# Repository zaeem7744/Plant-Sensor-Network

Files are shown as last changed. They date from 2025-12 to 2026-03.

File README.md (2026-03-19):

# :seedling: Plant Monitoring Sensor Network -- Complete IoT System








A production-ready full-stack IoT environmental monitoring system with **13 sensors**, battery + solar power, deep-sleep optimization achieving **~92% power savings**, and a real-time web dashboard. The system wakes every 30 minutes, reads all sensors, transmits data over Wi-Fi, and goes back to sleep -- designed to run **indefinitely on solar power**.

> **This is the firmware repository.** See also: [Backend API](https://github.com/zaeem7744/Plant-Sensor-Network-Backend) | [Web Dashboard](https://github.com/zaeem7744/Plant-Sensor-Network-Web-Dashboard)

---

## :camera: Screenshots

### Overview Dashboard -- System Status & 24h Averages
Shows total sensors, online/offline count, 1,786+ measurements recorded, and live sensor cards with real-time readings.

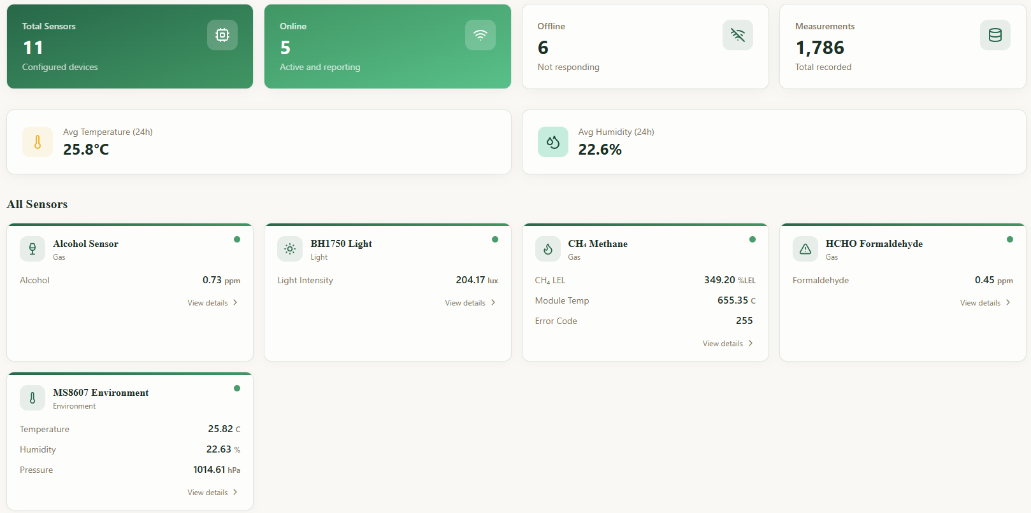
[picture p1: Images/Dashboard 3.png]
Dashboard Overview


### All Sensors View -- Live Readings Grid
13 environmental sensors displayed with real-time values, status indicators (green = online), and "View details" drill-down.

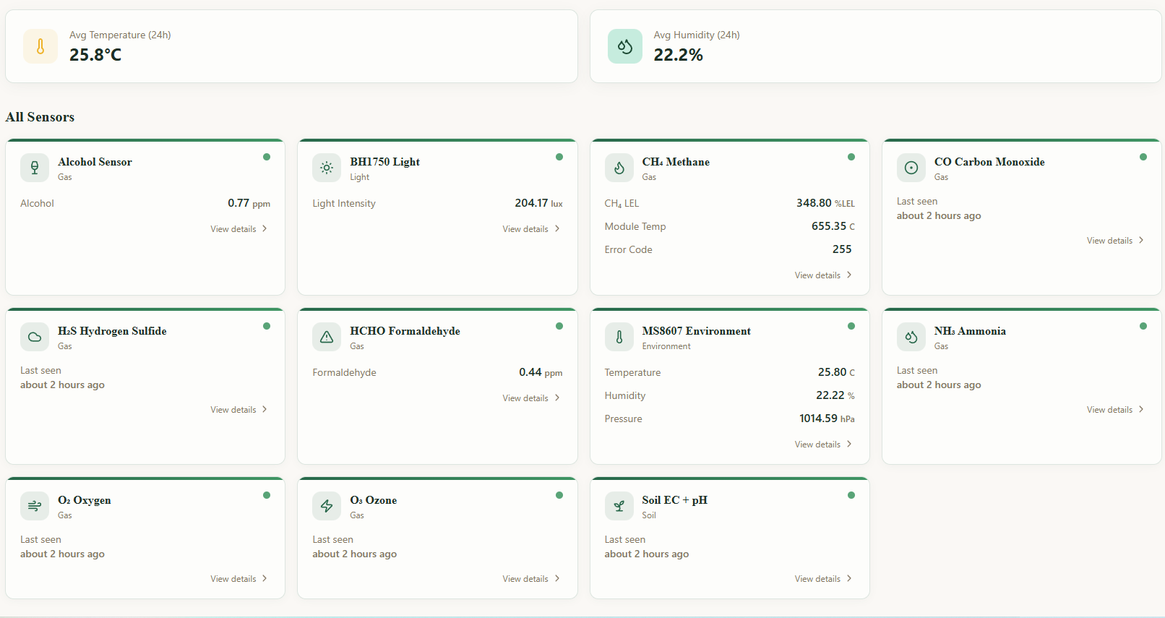
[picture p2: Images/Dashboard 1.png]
All Sensors


### Sensor Detail -- Historical Charts & Statistics
Individual sensor view with configurable time range (24h / 7d / 30d / All), interactive time-series chart, and min/max/avg statistics.

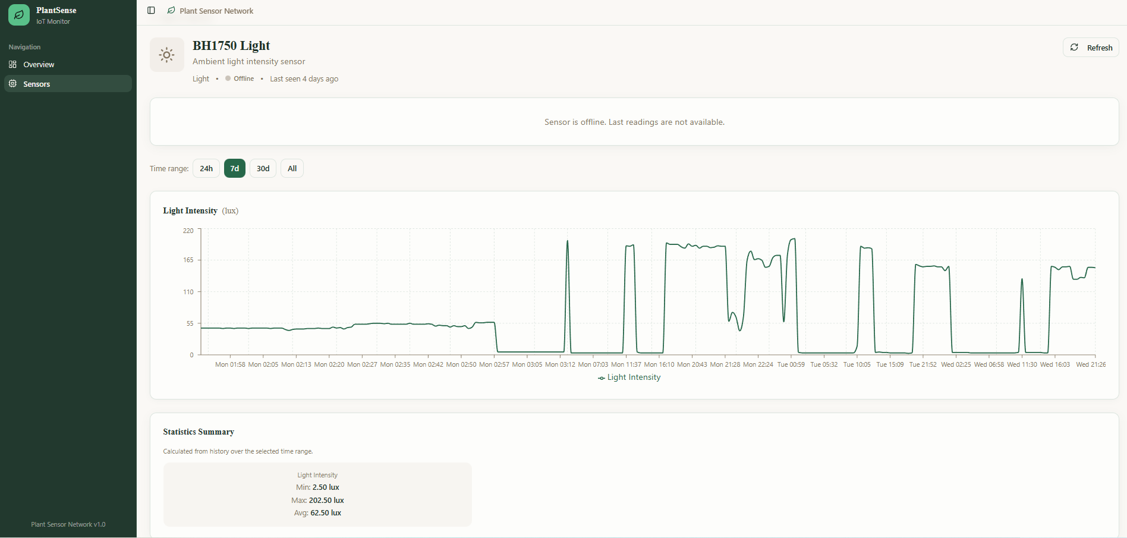
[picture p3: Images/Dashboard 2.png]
Sensor Detail


### Gas Sensors -- Category Filter
Filter sensors by category: Environment, Light, Gas, Soil. Showing 8 gas sensors monitoring CO, CH4, NH3, H2S, HCHO, O2, O3, and Alcohol.

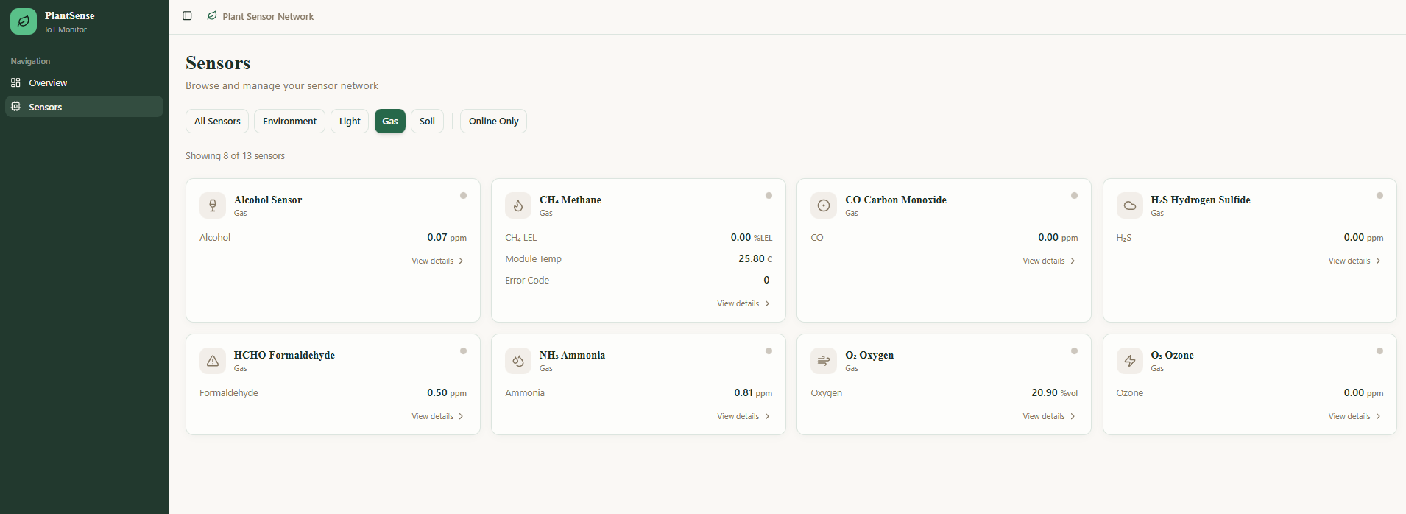
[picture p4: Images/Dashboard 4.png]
Gas Sensors


### Backend API -- FastAPI + Uvicorn Running
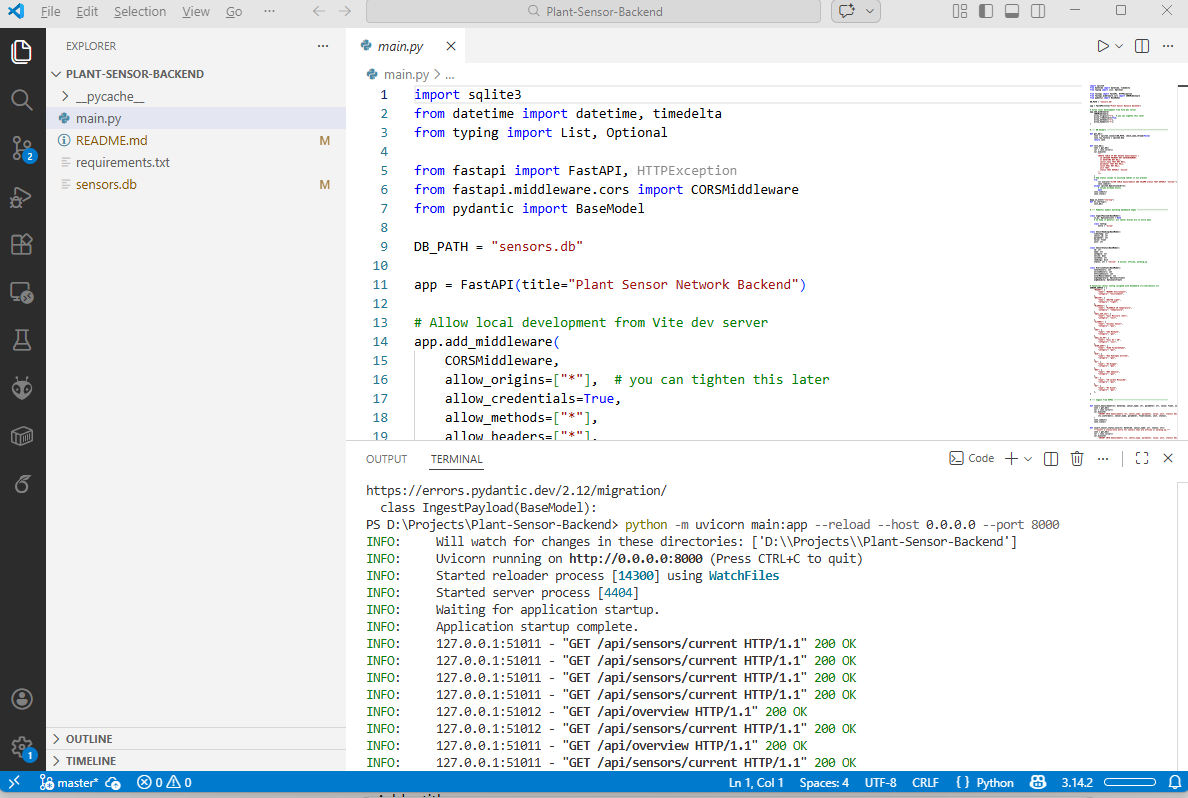
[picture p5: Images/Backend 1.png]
Backend


### Hardware Development -- Firmware & Sensor Testing
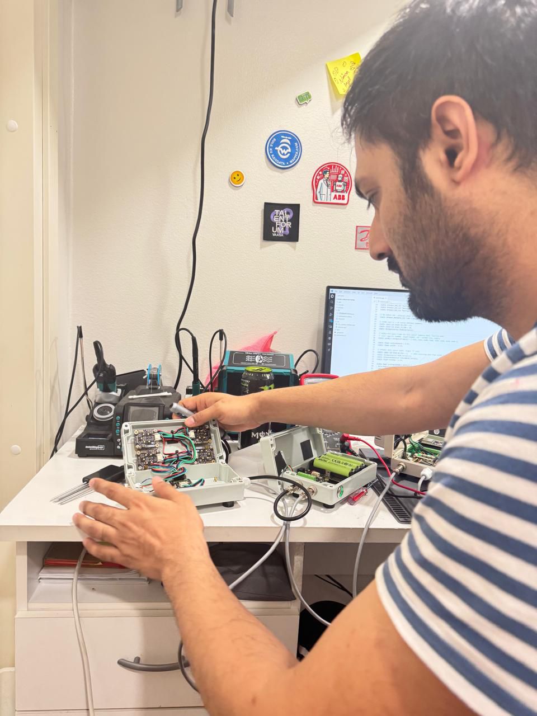
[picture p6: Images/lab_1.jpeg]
Firmware Development


### Lab Setup -- Oscilloscope, Multimeter & Sensor Node Enclosures
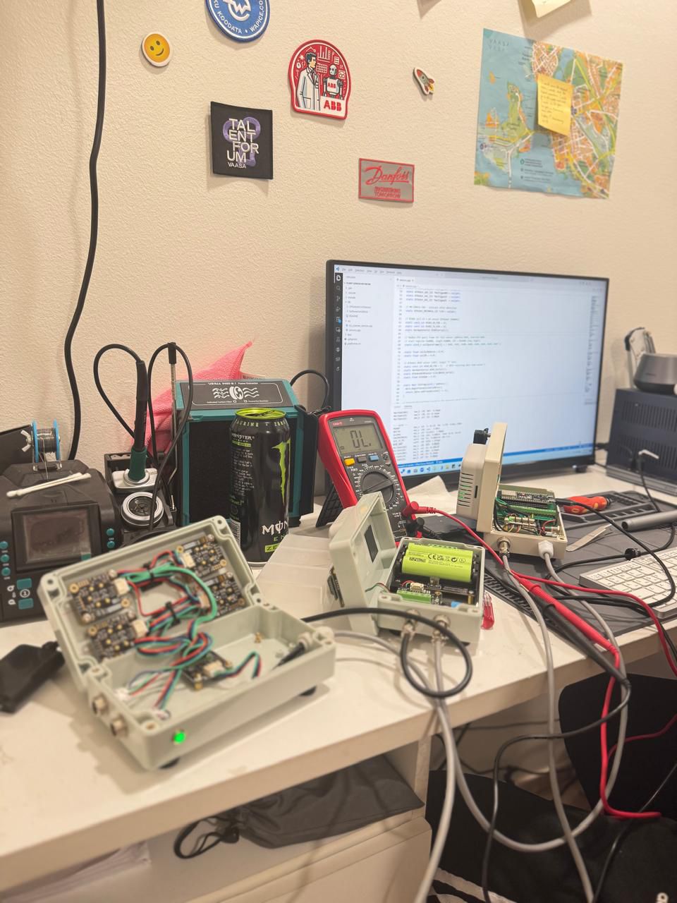
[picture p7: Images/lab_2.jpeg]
Lab Setup


### Hardware Debugging -- Probing Sensor Nodes
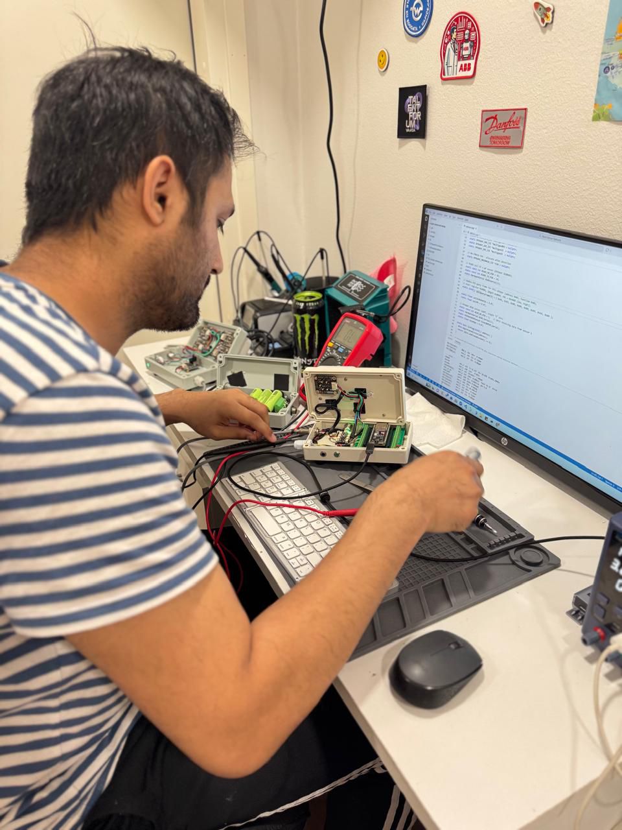
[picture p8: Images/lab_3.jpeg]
Hardware Testing


---

## :zap: Key Highlights

- **13 Environmental Sensors** with I2C multiplexing (2x TCA9548A) for address conflict resolution
- **~92% power savings** via deep sleep + MOSFET-switched sensor power rail
- **Solar-powered indefinite runtime** -- 10W panel generates 4.3x daily consumption
- **Battery backup** -- 3x 18650 cells (8,700 mAh), 5+ days without sunlight
- **Dual measurement cycle** -- status check then data upload for reliability
- **Production-ready dashboard** with real-time updates, historical charts, and statistics
- **Full-stack architecture** -- ESP32-S3 firmware + FastAPI backend + React/TypeScript frontend

---

## :building_construction: System Architecture

```
10W Solar Panel --> Charge Controller --> 3x 18650 Battery (8700 mAh)
                                              |
                                        Boost Converter (3.7V --> 5V)
                                              |
                    +-------------------------+-------------------------+
                    |                                                   |
              ESP32-S3 MCU                                   N-Channel MOSFET (GPIO 14)
         (always powered, ~20mA sleep)                              |
                    |                                        Sensor 5V Rail
                    |                                              |
              +-----+-----+                              All 13 Sensors (~300mA active)
              |           |
         Timer Wake   Button Wake -----> Double Measurement Cycle
         (30 min)     (GPIO 7)                    |
                                           WiFi POST --> FastAPI Backend --> SQLite DB
                                                                |
                                                    React Dashboard (live updates)
```

### Power States

| State | Current Draw | Duration | Description |
|---|---|---|---|
| **Active** | ~300 mA | ~8 sec | Sensors ON, reading + WiFi transmit |
| **Deep Sleep** | ~26 mA | ~1792 sec | ESP32 sleep + sensors OFF via MOSFET |
| **Average per cycle** | -- | 30 min | 13.62 mAh per cycle |
| **Daily consumption** | -- | 24h | ~653 mAh @ 5V (~3.27 Wh) |
| **Solar generation** | -- | 5h sun | ~2,800 mAh/day (4.3x surplus) |

---

## :satellite: Sensor Network

The system uses **two TCA9548A I2C multiplexers** to avoid address conflicts across 13 sensors:

| Sensor | Parameter(s) | Protocol | I2C Mux |
|---|---|---|---|
| MS8607 | Temperature, Humidity, Pressure | I2C | MUX_A (0x70) |
| BH1750 | Light Intensity (lux) | I2C | MUX_A |
| MLX90614 | IR Object Temperature | I2C | MUX_B (0x71) |
| Soil Moisture | Capacitive Moisture | I2C | MUX_B |
| Alcohol (MQ-135) | Alcohol concentration (ppm) | I2C/Analog | MUX_A |
| CH4 (MHZ9041A) | Methane (LEL) | I2C | MUX_A |
| Soil EC + pH | Conductivity, pH | UART2 (RS485) | -- |
| HCHO | Formaldehyde (ppm) | UART1 | -- |
| H2S | Hydrogen Sulfide (ppm) | I2C | MUX_A |
| O2 | Oxygen (%vol) | I2C | MUX_B |
| NH3 | Ammonia (ppm) | I2C | MUX_B |
| CO | Carbon Monoxide (ppm) | I2C | MUX_B |
| O3 | Ozone (ppm) | I2C | MUX_B |

### Hardware Connections

- **I2C Bus**: SDA = GPIO 8, SCL = GPIO 9
- **Sensor Power**: 5V rail controlled by N-Channel MOSFET (GPIO 14)
- **UART2 (Soil EC+pH)**: RX = GPIO 19, TX = GPIO 20 (RS485)
- **UART1 (HCHO)**: RX = GPIO 5
- **Wake Button**: GPIO 7 (internal pull-up)
- **Status LED**: Blue LED on GPIO 21

---

## :gear: Firmware Behavior

### Measurement Cycle (Dual-Cycle Approach)

Each wake-up performs **two measurement cycles** for reliability:

1. **Cycle 1 -- Status Check**: Power ON sensors --> Read all values --> Serial output --> Power OFF (no upload)
2. **Cycle 2 -- Data Upload**: Power ON sensors --> Read all values --> **POST to backend** --> Power OFF
3. **Deep Sleep**: Enter deep sleep for 30 minutes (wake on timer or button)

### JSON Payload Example

```json
{
  "ts_ms": 1234567,
  "MS8607": { "status": "online", "T": 24.3, "RH": 60.5, "P": 1013.2 },
  "BH1750": { "status": "online", "lux": 185.0 },
  "MULTIGAS": {
    "H2S": { "status": "online", "value": 0.0, "unit": "ppm" },
    "O2":  { "status": "online", "value": 20.9, "unit": "%vol" },
    "CO":  { "status": "online", "value": 0.0, "unit": "ppm" }
  },
  "summary": { "sensor_total": 13, "offline_count": 0 }
}
```

### Configurable Parameters

```cpp
SENSOR_SAMPLE_INTERVAL_MS = 1800000  // 30 min between wake cycles
SENSOR_POWER_WARMUP_MS    = 3000     // 3 sec sensor stabilization
SENSOR_MOSFET_PIN         = 14       // GPIO controlling sensor power
WAKE_BUTTON_PIN           = 7        // Manual wake-up button
STATUS_LED_PIN            = 21       // Blue status LED
```

### LED Status Indicators

- **Solid ON**: Device awake, WiFi connected
- **Rapid blink (5x)**: WiFi connection failed
- **Slow blink (1Hz)**: Awake but WiFi offline (button wake mode)
- **OFF**: Deep sleep

---

## :file_folder: Project Structure

```
Plant-Sensor-Network/
|-- Firmware/
|   +-- Plant Sensor Network/
|       |-- src/
|       |   |-- sensors.cpp          # Main sensor reading + WiFi logic
|       |   |-- config.h             # WiFi credentials + backend URL
|       |   +-- DFRobotHCHOSensor.h  # HCHO sensor library
|       +-- platformio.ini           # PlatformIO configuration
|-- Schemetic/                       # Circuit schematics and PCB files
|-- Images/                          # Dashboard and system screenshots
|-- Documents/                       # BOM, technical documentation
+-- Requirements/                    # System specifications
```

---

## :rocket: Quick Start

### 1. Configure Firmware
Edit `src/config.h`:
```cpp
#define WIFI_SSID     "YourWiFiNetwork"
#define WIFI_PASSWORD "YourPassword"
#define BACKEND_URL   "http://YOUR_PC_IP:8000/api/ingest"
```
Upload to ESP32-S3 via PlatformIO.

### 2. Start Backend
```bash
cd Plant-Sensor-Network-Backend
pip install -r requirements.txt
python -m uvicorn main:app --reload --host 0.0.0.0 --port 8000
```

### 3. Start Dashboard
```bash
cd Plant-Sensor-Network-Web-Dashboard
npm install
# Configure .env: VITE_BACKEND_URL=http://YOUR_PC_IP:8000
npm run dev
```

### 4. Power On ESP32
Device will: Connect to WiFi --> Measure --> Upload --> Deep sleep (30 min) --> Repeat

---

## :hammer_and_wrench: Tech Stack

| Component | Technology |
|---|---|
| **MCU** | ESP32-S3 |
| **Firmware** | C/C++ (PlatformIO) |
| **Backend** | [FastAPI + SQLite](https://github.com/zaeem7744/Plant-Sensor-Network-Backend) |
| **Frontend** | [React + TypeScript + Tailwind CSS](https://github.com/zaeem7744/Plant-Sensor-Network-Web-Dashboard) |
| **Protocols** | I2C, UART, RS485, Wi-Fi, HTTP REST |
| **Power** | 10W Solar + 3x 18650 batteries + MOSFET switching |
| **PCB Tools** | Schematic design files included |

---

## :bust_in_silhouette: Author

**Muhammad Zaeem Sarfraz** -- Electronics & IoT Hardware Engineer

- :link: [LinkedIn](https://www.linkedin.com/in/zaeemsarfraz7744/)
- :email: Zaeem.7744@gmail.com
- :earth_africa: Vaasa, Finland

---

*Document Version: 1.0 | Status: Production Ready | Last Updated: February 2026*

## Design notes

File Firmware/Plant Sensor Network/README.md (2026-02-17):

# Plant Sensor Network - ESP32-S3 Firmware

ESP32-S3 firmware for comprehensive environmental monitoring with deep sleep power management.

##  Features

- **13 Environmental Sensors**: Temperature, humidity, pressure, light, soil moisture, pH, EC, and multiple gas sensors
- **Deep Sleep Mode**: 30-minute sampling intervals with ~70% power savings
- **WiFi Connectivity**: Automatic data transmission to backend API
- **Dual Measurement Cycles**: Status check followed by reliable data upload
- **Manual Wake-up**: GPIO button for on-demand measurements
- **Status LED**: Visual feedback for device and WiFi status
- **I²C Multiplexing**: Two TCA9548A muxes handle address conflicts

##  Hardware Requirements

- **ESP32-S3** development board
- **Sensors** (DFRobot and compatible modules):
  - MS8607 (Temperature, Humidity, Pressure)
  - BH1750 (Light)
  - MLX90614 (IR Temperature)
  - Soil Moisture (I²C Capacitive)
  - Alcohol, CH4, H2S, O2, NH3, CO, O3 (Gas sensors)
  - Soil EC + pH (UART)
  - HCHO (UART)
- **Two I²C Multiplexers**: TCA9548A or PCA9548A (addresses 0x70, 0x71)
- **MOSFET**: N-channel for 5V sensor power control (GPIO 14)
- **Button**: Wake-up button on GPIO 7 (pull-up integrated in ESP32)
- **Status LED**: Blue LED on GPIO 21 (with 4.7kΩ series resistor)
- **Power LEDs**: Green LEDs on sensor boxes (always ON when powered)

### Power Supply

- **Battery**: 3× 18650 Li-ion cells in parallel (2900 mAh each = **8700 mAh total**)
- **Voltage**: 3.7V nominal per cell
- **Boost Converter**: Generates stable 5V for ESP32 and sensors
- **Solar Panel**: 10W @ 18V for continuous charging (optional)

##  Pin Configuration

| Function | GPIO | Notes |
|---|---|---|
| I²C SDA | 8 | Connect to both multiplexers |
| I²C SCL | 9 | Connect to both multiplexers |
| Sensor Power | 14 | MOSFET gate (controls 5V rail) |
| UART2 RX (Soil EC+pH) | 19 | RS485 module |
| UART2 TX (Soil EC+pH) | 20 | RS485 module |
| UART1 RX (HCHO) | 5 | HCHO sensor |
| Wake Button | 7 | Button to GND (internal pull-up) |
| Status LED | 21 | Blue LED + 4.7kΩ resistor to GND |

##  Quick Start

### 1. Install PlatformIO

Install PlatformIO via VS Code extension or CLI:
- **VS Code**: Install "PlatformIO IDE" extension
- **CLI**: Follow [PlatformIO installation guide](https://platformio.org/install/cli)

### 2. Configure WiFi and Backend

Edit `src/config.h`:

```cpp
#define WIFI_SSID "YourWiFiNetwork"
#define WIFI_PASSWORD "YourWiFiPassword"
#define BACKEND_URL "http://YOUR_PC_IP:8000/api/ingest"
```

Replace:
- `YourWiFiNetwork` with your WiFi SSID
- `YourWiFiPassword` with your WiFi password
- `YOUR_PC_IP` with the IP address of your backend server

### 3. Upload Firmware

```bash
# From this directory
pio run --target upload

# Or use VS Code PlatformIO toolbar: Upload button
```

### 4. Monitor Serial Output

```bash
pio device monitor

# Or use VS Code PlatformIO toolbar: Serial Monitor
```

##  Configuration Parameters

Edit `src/sensors.cpp` to adjust timing:

```cpp
// Wake-up interval (default: 30 minutes)
static const uint32_t SENSOR_SAMPLE_INTERVAL_MS = 1800000;

// Sensor warm-up time (default: 3 seconds)
static const uint32_t SENSOR_POWER_WARMUP_MS = 3000;

// Button active duration (default: 30 seconds)
static const uint32_t BUTTON_ACTIVE_TIME_MS = 30000;
```

**Common Intervals:**
- 5 minutes: `300000`
- 10 minutes: `600000`
- 30 minutes: `1800000` (default)
- 1 hour: `3600000`

##  Power Management

### Power Optimization Journey

The system underwent extensive power optimization to achieve maximum battery life:

**Initial Configuration (Always-ON)**:
- All sensors continuously powered
- ESP32 always active (no sleep)
- Peak current: **330-340 mA** (with methane + pH sensors)
- Daily consumption: ~8 Ah/day
- **Battery life: ~1 day** 

**Step 1: Identify High-Power Components**
- Methane sensor: Consumes ~140 mA
- pH probe: Causes ~40 mA spikes
- VOC sensors: ~37 mA combined
- Remaining sensors + ESP32: ~141 mA

**Step 2: MOSFET Power Switching**
- Added N-channel MOSFET on GPIO 14 to control sensor 5V rail
- Sensors powered ON only during readings
- Sensors OFF current: **6 mA** (vs 300 mA active)
- Power savings: **~98%** during idle 

**Step 3: ESP32 Deep Sleep**
- ESP32 always-on current: ~60 mA
- Optimized deep sleep current: **~20 mA**
- Power savings: **~67%** when sleeping 

**Final Optimized Configuration**:
- Sensors: Powered ON for ~8 seconds per cycle, OFF otherwise
- ESP32: Deep sleep between measurements (30-minute intervals)
- **Active current**: ~300 mA for 8 seconds
- **Sleep current**: ~26 mA (6 mA sensors OFF + 20 mA ESP32 deep sleep)
- **Overall power savings: ~92% compared to always-on design**

### Deep Sleep Mode

The firmware implements aggressive power saving:

1. **Active Period** (~8 seconds per 30-minute cycle):
   - Wake from deep sleep
   - Power ON sensors via MOSFET (GPIO 14)
   - Wait 3 seconds for sensor warm-up
   - Perform two measurement cycles
   - Upload data to backend via WiFi
   - Power OFF sensors via MOSFET
   - Enter deep sleep

2. **Deep Sleep** (~29 minutes 52 seconds):
   - ESP32 deep sleep: ~20 mA
   - Sensors powered OFF via MOSFET: ~6 mA
   - **Total sleep current: ~26 mA**
   - Wake-up sources: Timer or button (GPIO 7)

### Measured Power Consumption

| State | Current @ 5V | Duration (30-min cycle) | Energy |
|---|---|---|---|
| **Active (measuring)** | ~300 mA | ~8 seconds | 0.67 mAh |
| **Deep Sleep** | ~26 mA | ~1792 seconds | 12.95 mAh |
| **Average per cycle** | - | 1800 seconds (30 min) | **13.62 mAh** |

**Daily Consumption** (48 cycles):
- **653 mAh/day @ 5V** = **3.27 Wh/day**

### Battery Life Calculations

**With 8700 mAh Battery Pack (3× 18650 cells)**:

**Battery-only operation** (no solar):
- Usable capacity: 8700 mAh × 80% = 6960 mAh (80% DoD recommended)
- Runtime: 6960 mAh ÷ 653 mAh/day ≈ **5 days**

**With 10W Solar Panel**:
- Panel output: 10W @ 18V = ~0.56A peak
- Realistic daily generation (5 hours sunlight): 0.56A × 5h = **2.8 Ah/day**
- System consumption: 0.653 Ah/day
- **Net gain: +2.15 Ah/day** (surplus charges battery)
- **Runtime: Indefinite**  (solar exceeds consumption by 4.3×)

**Cloudy day scenario** (1 hour effective sunlight):
- Solar generation: 0.56 Ah/day
- Net deficit: -0.653 + 0.56 = **-0.09 Ah/day** (slight deficit)
- Battery can sustain system for **30 days** on cloudy weather before full discharge

**No sunlight for extended period**:
- Battery lasts **~5 days** before requiring recharge

### Power Savings Summary

| Configuration | Daily Consumption | Battery Life (8700 mAh) | Improvement |
|---|---|---|---|
| **Always-ON** | ~8000 mAh | 1.1 days | Baseline |
| **With optimizations** | ~653 mAh | 5 days | **5× longer** |
| **With 10W solar** | Net positive | Indefinite | **Infinte** |

*Actual battery life depends on WiFi signal strength, temperature, sensor warm-up time, and solar panel exposure.*

##  Firmware Behavior

### Dual Measurement Cycle

Each wake-up performs **two complete cycles**:

1. **First Cycle (Status Check)**:
   - Read all sensors
   - Output to serial monitor
   - **Do NOT** post to backend
   - Used for reliability verification

2. **Second Cycle (Data Upload)**:
   - Read all sensors again
   - Output to serial monitor
   - **POST data** to backend API
   - Complete JSON printed with `COMPLETE JSON=` prefix

### Wake-up Sources

**Timer Wake-up (Automatic)**:
- Wakes every 30 minutes (configurable)
- Performs dual cycle
- Returns to deep sleep immediately

**Button Wake-up (Manual)**:
- Press button on GPIO 7
- Performs dual cycle
- Stays active for 30 seconds (LED on)
- Returns to deep sleep after timeout

### LED Status Indicators

**Blue Status LED (GPIO 21)**:

| Pattern | Meaning |
|---|---|
| Solid ON | Device awake, WiFi connected |
| Rapid blink (5×) | WiFi connection failed |
| Slow blink (1 Hz) | Button mode, WiFi offline |
| OFF | Deep sleep mode |

**Green Power LEDs (on sensor boxes)**:
- Always ON when sensors are powered (MOSFET enabled)
- OFF when sensors are unpowered (deep sleep)
- Not software-controllable

##  Data Format

### JSON Payload Structure

```json
{
  "ts_ms": 1234567890,
  "MS8607": {
    "status": "online",
    "T": 24.5,
    "RH": 60.2,
    "P": 1013.25
  },
  "BH1750": {
    "status": "online",
    "lux": 185.0
  },
  "MLX90614": {
    "status": "online",
    "T_object": 19.8
  },
  "SOIL_CAP_I2C": {
    "status": "online",
    "moisture": 450
  },
  "ALCOHOL": {
    "status": "online",
    "value": 12.5
  },
  "CH4": {
    "status": "online",
    "value": 0.0
  },
  "SOIL_EC_PH": {
    "status": "online",
    "ec": 0.8,
    "ph": 6.5
  },
  "HCHO_UART": {
    "status": "online",
    "value": 0.01
  },
  "MULTIGAS": {
    "H2S": {"status": "online", "value": 0.0, "unit": "ppm"},
    "O2": {"status": "online", "value": 20.9, "unit": "%vol"},
    "NH3": {"status": "online", "value": 0.3, "unit": "ppm"},
    "CO": {"status": "online", "value": 0.0, "unit": "ppm"},
    "O3": {"status": "online", "value": 0.0, "unit": "ppm"}
  },
  "summary": {
    "sensor_total": 13,
    "offline_count": 0,
    "offline_list": ""
  }
}
```

**Status Field**: Each sensor reports one of:
- `"online"` – Successfully read
- `"offline"` – Failed to read or not responding
- `"warming_up"` – Sensor still stabilizing

## Troubleshooting

### WiFi Connection Issues

**LED blinks rapidly 5 times:**
- Verify WiFi credentials in `config.h`
- Check WiFi signal strength
- Ensure 2.4 GHz WiFi (ESP32 doesn't support 5 GHz)
- Confirm backend server is accessible on local network

**Device connects but data not received:**
- Verify backend URL includes `/api/ingest` endpoint
- Check backend server is running on specified port
- Confirm firewall allows incoming connections on port 8000

### Sensor Reading Issues

**Sensor shows "offline" status:**
- Check I²C wiring (SDA = GPIO 8, SCL = GPIO 9)
- Verify sensor power supply (5V via MOSFET on GPIO 14)
- Ensure correct I²C multiplexer channel assignment
- Check serial monitor for initialization errors

**I²C bus errors:**
- Reduce I²C speed in `platformio.ini` (not typically needed)
- Add pull-up resistors (4.7kΩ) on SDA/SCL lines
- Verify no address conflicts (use `i2cdetect` equivalent)

### Serial Monitor Output

**No output on serial monitor:**
- Baud rate must be **115200**
- Check USB cable supports data (not charge-only)
- Press reset button on ESP32

**Garbled output:**
- Set baud rate to 115200
- Check for brownout (power supply issue)

##  Additional Documentation

- **Main Documentation**: See `PROJECT_DELIVERY_DOCUMENTATION.md` in project root for complete system overview
- **Sensor Details**: Visit [DFRobot](https://www.dfrobot.com/) for sensor datasheets and specifications

## 🔗 Related Repositories

This firmware works with:
- **Backend API**: FastAPI server with SQLite database
- **Web Dashboard**: React-based real-time monitoring interface

See main project documentation for complete system setup.

##  Acknowledgments

Sensor hardware sourced from [DFRobot](https://www.dfrobot.com/).

---

**Firmware Version**: 1.0  
**Last Updated**: February 2026  
**Board**: ESP32-S3  
**Framework**: Arduino (via PlatformIO)

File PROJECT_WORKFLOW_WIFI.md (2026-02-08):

# Plant Monitoring Sensor Network – Wi‑Fi Workflow Summary

## 1. Project Basics
- **Project Name:** Plant Monitoring Sensor Network (Wi‑Fi MVP)
- **Client Name:** John Bambery
- **Scope:** Two battery‑powered, weatherproof sensor nodes + one local Wi‑Fi backend + web dashboard
- **Communication:** Wi‑Fi only (no LoRa in current phase)
- **Data Path (high level):** Sensors → ESP32 nodes → Wi‑Fi → Python FastAPI backend (SQLite) → React/Vite web dashboard

---

## 2. High‑Level System Architecture
- **Sensor Node (per node)**
  - ESP32‑S3 microcontroller
  - Environmental sensors (temperature, humidity, pressure, light, soil EC/pH, etc.)
  - Gas / VOC sensors (e.g. H2S, NH3, CO, O3, alcohol, formaldehyde)
  - RS485 / UART / I²C buses with muxes
  - Li‑ion battery + (optional) solar charging
  - Weatherproof enclosure + cable glands
- **Network & Backend**
  - Node connects to local Wi‑Fi (2.4 GHz)
  - HTTP POST JSON to backend: `http://PC_LAN_IP:8000/api/ingest`
  - Backend: FastAPI + SQLite (`sensors.db`)
  - API endpoints: `/api/ingest`, `/api/sensors/current`, `/api/sensors/history`, `/api/overview`, `/api/health`
- **Web Dashboard**
  - React/Vite/Lovable app on client PC
  - Uses `VITE_BACKEND_URL=http://PC_LAN_IP:8000`
  - Views: Overview, Sensors list, Sensor detail/history charts

---

## 3. End‑to‑End Workflow (Linear Steps)

1. **Node Power‑Up & Wi‑Fi Join**
   - ESP32 powers from battery
   - ESP32 reads Wi‑Fi SSID/password from `config.h`
   - ESP32 connects to project Wi‑Fi and obtains IP address

2. **Sensor Measurement Cycle (per loop)**
   - Select active I²C mux channels
   - Read environmental sensors (MS8607, BH1750, soil EC/pH, etc.)
   - Read gas sensors (MULTIGAS, CH4, alcohol, HCHO)
   - Update local health/diagnostic flags

3. **Build JSON Payload on ESP32**
   - Create root object: `ts_ms` (millis since boot)
   - Add nested objects for each sensor:
     - `MS8607` → `T`, `RH`, `P`
     - `BH1750` → `lux`
     - `ALCOHOL` → `ppm`
     - `CH4` → `lel_pct`, `tempC`, `err`
     - `HCHO_UART` → `ppm`
     - `SOIL_EC_PH` → `ec_mS_per_cm`, `pH` (when available)
     - `MULTIGAS` → `H2S`, `O2`, `NH3`, `CO`, `O3` blocks
   - Add `summary` block: total sensors, offline count, offline list

4. **Wi‑Fi HTTP POST to Backend**
   - If `WiFi.status() == WL_CONNECTED`:
     - `HTTPClient` POST to `BACKEND_URL`
     - Content‑Type: `application/json`
     - Log HTTP status and any error to serial

5. **Backend Ingest & Storage**
   - FastAPI `/api/ingest` receives JSON
   - Use server local time `ts = datetime.now()` as canonical timestamp
   - For each sensor block:
     - Map fields to logical parameters (e.g. `temperature_c`, `humidity_rh`, `co_ppm`, `o2_percent_vol`)
     - Insert rows into `measurements` table:
       - `ts`, `sensor_name`, `parameter`, `value`, `unit`
   - Result: time‑series data appended to `sensors.db`

6. **Backend Aggregation for Dashboard**
   - `/api/sensors/current`:
     - For each `(sensor_name, parameter)`, select latest `ts`
     - Group by `sensor_name` and package into `SensorStatus` objects
     - Mark `online` if `lastSeen >= now - 10 s`
   - `/api/sensors/history`:
     - Filter `measurements` by `sensor_name`, `parameter`, `ts >= now - hours`
     - Return ordered list for charts
   - `/api/overview`:
     - Count total sensors, online, offline
     - Count total measurement rows
     - Compute 24h averages for `temperature_c` and `humidity_rh` from MS8607

7. **Web Dashboard Display**
   - Frontend polls backend every few seconds:
     - `/api/sensors/current` for cards
     - `/api/overview` for top stats
   - Sensor cards:
     - Show sensor name, category, online badge
     - Display latest values for main parameters
     - If offline, show "Last seen X minutes ago" (from `lastSeen`)
   - Sensor detail page:
     - Summary of current readings
     - Time‑range selector (24h, 7d, 30d, All)
     - Charts from `/api/sensors/history`
     - Statistics summary (min / max / avg from history)

8. **User Monitoring & Interaction**
   - User opens dashboard URL (e.g. `http://localhost:5173`)
   - User filters sensors by category (Environment / Light / Gas / Soil)
   - User drills into specific sensors for historical analysis

---

## 4. Firmware / Hardware Task Breakdown (Wi‑Fi Only)

- **Hardware Selection & Assembly**
  - Choose ESP32‑S3 devkit and all required sensors
  - Design wiring: I²C buses, mux channels, UART, RS485, power rails
  - Assemble prototype on breadboard
  - Move to PCB + enclosure once stable

- **Firmware Core (ESP32)**
  - Wi‑Fi connect logic using `config.h`
  - I²C mux helper functions and sensor initialisation
  - Per‑cycle sensor read functions with offline detection
  - JSON build using ArduinoJson (including `MULTIGAS` block)
  - HTTP POST implementation and basic retry/error logging
  - Simple diagnostics over serial (sensor summary, HTTP status)

- **Power & Enclosure**
  - Select Li‑ion battery and protection circuitry
  - Integrate optional solar charger
  - Design IP‑rated enclosure and cable routing
  - Add LED indicators for status (power, Wi‑Fi, error)

---

## 5. Backend & Dashboard Task Breakdown

- **Backend (FastAPI + SQLite)**
  - Define Pydantic models for ingest and API responses
  - Implement `/api/ingest` mapping from firmware JSON → DB rows
  - Implement `/api/sensors/current`, `/api/sensors/history`, `/api/overview`, `/api/health`
  - Add CORS rules for local Vite dev server
  - Add simple logging and debug prints (ingest keys, MULTIGAS keys)

- **Database (SQLite)**
  - Create `measurements` table
  - Optionally add indexes on `(sensor_name, parameter, ts)`
  - Plan retention policy if DB grows beyond a few GB (e.g. delete >90 days)

- **Web Dashboard (React/Vite)**
  - `.env` with `VITE_BACKEND_URL`
  - `useSensorData` + `useSensorHistory` hooks to call backend
  - Sensor list, filters, and cards
  - Sensor detail page with charts and stats
  - Overview page with total sensors, online/offline, total measurements, averages

---

## 6. Notes for Future Extensions (NOT in current Wi‑Fi MVP)

- Add LoRa branch for long‑range communication (ESP32 + LoRa transceivers)
- Add central LoRa "gateway" node that forwards data to the same FastAPI backend
- Add cloud IoT integration (MQTT/HTTPS) as an alternate data path
- Add remote configuration (sampling interval, thresholds) via backend APIs

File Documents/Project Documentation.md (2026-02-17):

# Plant Sensor Monitoring Network – Project Documentation

## Introduction

Thank you for the opportunity to work on this comprehensive IoT sensor monitoring system. This document provides an overview of the complete Plant Sensor Monitoring Network project, including firmware, backend, and web dashboard components.

The system has been designed with power efficiency and reliability in mind, utilizing deep sleep modes and robust sensor integration to provide long-term environmental monitoring capabilities.

---

## 1. Project Overview

This project implements a complete wireless sensor monitoring system consisting of three main components:

1. **ESP32-S3 Firmware** – Embedded firmware for sensor data acquisition and wireless transmission
2. **FastAPI Backend** – Python-based REST API server with SQLite database
3. **React Web Dashboard** – Real-time visualization and historical data analysis

### Key Features

- **13 Environmental Sensors** monitoring air quality, soil conditions, temperature, humidity, and more
- **Deep Sleep Power Management** – Device sleeps between measurements for optimized battery life
- **WiFi Connectivity** – Automatic data transmission to backend server
- **Real-time Dashboard** – Live sensor readings with historical charting
- **Status Tracking** – Online/offline sensor status with last-seen timestamps
- **Dual Measurement Cycles** – Status check followed by data upload for reliability

---

## 2. Repository Structure

The project is organized into three main directories:

### Firmware (ESP32-S3)
```
Plant Monitoring Sensor Network/Firmware/Plant Sensor Network/
├── src/
│   ├── sensors.cpp          # Main sensor reading and WiFi logic
│   ├── config.h             # WiFi credentials and backend URL
│   └── DFRobotHCHOSensor.h  # HCHO sensor library
├── platformio.ini            # PlatformIO configuration
```

**Key Configuration Parameters** (in `src/sensors.cpp`):
- `SENSOR_SAMPLE_INTERVAL_MS = 1800000` (30 minutes) – Time between wake cycles
- `SENSOR_POWER_WARMUP_MS = 3000` (3 seconds) – Sensor stabilization time
- `SENSOR_MOSFET_PIN = 14` – GPIO controlling sensor power rail
- `WAKE_BUTTON_PIN = 7` – Button for manual wake-up
- `STATUS_LED_PIN = 21` – LED status indicator

### Backend (FastAPI + SQLite)
```
D:\Projects\plant-sensor-backend/
├── main.py           # FastAPI server with all API endpoints
├── sensors.db        # SQLite database (auto-created)
├── requirements.txt  # Python dependencies
└── README.md         # Backend documentation
```

**Note**: Backend is located at `plant-sensor-backend\` (outside main project folder)

**Run Command:**
```bash
python -m uvicorn main:app --reload --host 0.0.0.0 --port 8000
```

### Web Dashboard (React + Vite)
```
Plant-Sensor-Network-Web-Dashboard/
├── src/
│   ├── components/        # React UI components
│   ├── lib/sensors.ts     # Sensor configuration
│   ├── hooks/             # Data fetching hooks
│   └── pages/             # Dashboard pages
├── .env                   # Backend URL configuration
└── package.json
```

**Run Command:**
```bash
npm run dev
```

**Environment Configuration** (`.env`):
```
VITE_BACKEND_URL=http://YOUR_PC_LAN_IP:8000
```

---

## 📊 System Architecture

### High-Level Data Flow

```
ESP32-S3 Firmware
    ↓ (Deep Sleep: 30 minutes)
    ↓ (Wake up: Timer or Button)
    ↓ (Power ON sensors via MOSFET)
    ↓ (Read 13 sensors via I²C/UART)
    ↓ (Build JSON payload with status)
    ↓
WiFi POST → Backend API (/api/ingest)
    ↓
SQLite Database (measurements table)
    ↓
Backend REST API
    ↓ (/api/sensors/current)
    ↓ (/api/sensors/history)
    ↓ (/api/overview)
    ↓
React Dashboard
    ↓ (Real-time updates every few seconds)
    ↓ (Charts, statistics, sensor cards)
    ↓
User View (Browser)
```

### Hardware Power Architecture

```
10W Solar Panel 
    ↓
Charge Controller
    ↓
3× 18650 Battery Pack (8700 mAh @ 3.7V)
    ↓
Boost Converter (3.7V → 5V)
    ↓
    ├──> ESP32-S3 (always powered)
    │
    └──> N-Channel MOSFET (GPIO 14)
            ↓
        Sensor 5V Rail
            ↓
        All 13 Sensors (switched ON/OFF)

Power States:
- Active: ESP32 + Sensors = ~300 mA (8 sec)
- Sleep: ESP32 deep sleep + Sensors OFF = ~26 mA (1792 sec)
```

### Power Management

The ESP32-S3 implements sophisticated power management:

1. **Deep Sleep Mode**: Device sleeps for 30 minutes between measurements
   - ESP32 deep sleep current: ~20 mA (optimized)
   - Sensors OFF current: ~6 mA (via MOSFET)
   - **Total sleep current: ~26 mA**
   - **Power savings: ~92% compared to always-on operation**

2. **Sensor Power Control**: MOSFET on GPIO 14 controls 5V sensor rail
   - Sensors powered OFF during sleep (reduces ~300 mA to ~6 mA)
   - 3-second warm-up period after power-on
   - 98% power savings during idle periods

3. **Wake-up Sources**:
   - **Timer**: Automatic wake every 30 minutes for scheduled measurements
   - **Button** (GPIO 7): Manual wake-up, stays active for 30 seconds

4. **Measured Power Consumption**:
   - **Active (measuring)**: ~300 mA for ~8 seconds (0.67 mAh)
   - **Deep sleep**: ~26 mA for ~1792 seconds (12.95 mAh)
   - **Average per cycle**: 13.62 mAh per 30-minute cycle
   - **Daily consumption**: ~653 mAh @ 5V = ~3.27 Wh/day

5. **Battery Configuration**:
   - **3× 18650 Li-ion cells** in parallel (2900 mAh each)
   - **Total capacity**: 8700 mAh @ 3.7V nominal
   - **Boost converter**: Generates stable 5V for system
   - **Battery-only runtime**: ~5 days (with 80% DoD) (It may go beyond 7 days just for the safe side)

6. **Solar Charging**:
   - **10W solar panel @ 18V** provides continuous charging
   - Daily generation (5h sunlight): ~2.8 Ah/day
   - System consumption: ~0.653 Ah/day
   - **Net surplus**: +2.15 Ah/day (4.3× excess capacity)
   - **Runtime with solar**: Indefinite ♾️
   - **Cloudy days** (1h sunlight): -0.09 Ah/day deficit, but battery lasts 30+ days

---

## 4. Sensor Network

The system monitors 13 environmental parameters using professional DFRobot sensors and other industrial-grade modules.

### Sensor List

| Sensor | Parameter(s) | Category | I²C Mux |
|---|---|---|---|
| MS8607 | Temperature, Humidity, Pressure | Environment | MUX_A (0x70) |
| BH1750 | Light Intensity | Light | MUX_A |
| MLX90614 | IR Object Temperature | Temperature | MUX_B (0x71) |
| Soil Moisture (I²C) | Capacitive Moisture | Soil | MUX_B |
| Alcohol Sensor | Alcohol Concentration | Gas | MUX_A |
| CH4 (MHZ9041A) | Methane | Gas | MUX_A |
| Soil EC + pH | Conductivity, pH | Soil | UART2 (RS485) |
| HCHO | Formaldehyde | Gas | UART1 |
| H₂S | Hydrogen Sulfide | Gas | MUX_A |
| O₂ | Oxygen | Gas | MUX_B |
| NH₃ | Ammonia | Gas | MUX_B |
| CO | Carbon Monoxide | Gas | MUX_B |
| O₃ | Ozone | Gas | MUX_B |

### I²C Multiplexer Architecture

The system uses **two TCA9548A/PCA9548A I²C multiplexers** to avoid address conflicts:

- **MUX_A (0x70)**: MS8607, BH1750, Alcohol, CH4, H₂S
- **MUX_B (0x71)**: MLX90614, Soil Moisture, O₂, NH₃, CO, O₃

**Important**: Only one mux channel is active at a time to prevent I²C bus collisions.

### Hardware Connections

- **I²C Bus**: SDA = GPIO 8, SCL = GPIO 9
- **Sensor Power**: 5V rail controlled by MOSFET (GPIO 14)
- **UART2 (Soil EC+pH)**: RX = GPIO 19, TX = GPIO 20
- **UART1 (HCHO)**: RX = GPIO 5
- **Wake Button**: GPIO 7 (internal pull-up enabled)
- **Status LED**: Blue LED on GPIO 21 (with 4.7kΩ series resistor)
- **Power LEDs**: Green LEDs on all sensor boxes (always ON when powered)

### Sensor Data Accuracy

**Tested and Validated:**
- MS8607 (Temperature, Humidity, Pressure)
- BH1750 (Light)
- MLX90614 (IR Temperature)
- Soil Moisture (Capacitive)
- H₂S (Hydrogen Sulfide) – environmentally safe levels
- O₂ (Oxygen) – shows clear variations with ventilation

**Calibrated but Not Fully Tested:**
- **NH₃ (Ammonia)**: Sensor is functional but not tested with actual ammonia gas due to safety concerns
- **CH₄ (Methane)**: Library and communication verified; gas testing requires controlled environment
- **CO (Carbon Monoxide)**: Sensor responds to baseline air quality; harmful concentrations not tested

These sensors require harmful or dangerous gases for full validation, which cannot be safely produced in a standard development environment. The sensors are properly configured and show expected baseline readings. For detailed specifications and calibration data, please refer to the [DFRobot website](https://www.dfrobot.com/), where all sensors were sourced.

---

## 5. Firmware Behavior

### Measurement Cycle (Dual-Cycle Approach)

Each wake-up performs **two measurement cycles**:

1. **First Cycle (Status Check)**:
   - Powers ON sensors
   - Reads all sensor values
   - Prints to serial monitor
   - Does NOT post to backend
   - Powers OFF sensors

2. **Second Cycle (Data Upload)**:
   - Powers ON sensors
   - Reads all sensor values
   - Prints to serial monitor
   - **POSTS data to backend**
   - Powers OFF sensors

3. **Deep Sleep**:
   - Enters deep sleep for 30 minutes
   - Wakes on timer or button press

### JSON Payload Structure

The firmware sends a complete JSON document to the backend API:

```json
{
  "ts_ms": 1234567,
  "MS8607": {
    "status": "online",
    "T": 24.3,
    "RH": 60.5,
    "P": 1013.2
  },
  "BH1750": {
    "status": "online",
    "lux": 185.0
  },
  "MLX90614": {
    "status": "online",
    "T_object": 19.5
  },
  "MULTIGAS": {
    "H2S": {"status": "online", "value": 0.0, "unit": "ppm"},
    "O2": {"status": "online", "value": 20.9, "unit": "%vol"},
    "NH3": {"status": "online", "value": 0.4, "unit": "ppm"},
    "CO": {"status": "online", "value": 0.0, "unit": "ppm"},
    "O3": {"status": "online", "value": 0.0, "unit": "ppm"}
  },
  "summary": {
    "sensor_total": 13,
    "offline_count": 0,
    "offline_list": ""
  }
}
```

**Key Features:**
- Every sensor includes a `"status"` field: `"online"`, `"offline"`, or `"warming_up"`
- Summary object provides quick overview of system health
- All sensors appear in JSON even if offline (for tracking)

### LED Status Indicators on Modue 2 (Box)

**Blue Status LED (GPIO 21)**:
- **LED ON (solid)**: Device awake, WiFi connected
- **LED OFF**: Device in deep sleep
- **Rapid blink (5×)**: WiFi connection failed
- **Slow blink (1Hz)**: Device awake but WiFi offline (button wake mode)

**Green Power LEDs (on sensor Moule boxes)**:
- Always ON when MOSFET powers sensors
- OFF when sensors unpowered during sleep
- Hardware indicators, not software-controllable

### Button Wake-up (GPIO 7)

Press button → Device wakes immediately:
1. Performs double measurement cycle
2. Sends data to backend
3. Stays active for 30 seconds (LED on)
4. Returns to deep sleep

**Hardware**: Button connects GPIO 7 to GND when pressed. ESP32 internal pull-up enabled. GPIO hold feature maintains pin state during sleep.

### Configurable Parameters

You can adjust timing by editing `src/sensors.cpp`:

```cpp
// Change wake-up interval (currently 30 minutes)
static const uint32_t SENSOR_SAMPLE_INTERVAL_MS = 1800000;

// Change sensor warm-up time (currently 3 seconds)
static const uint32_t SENSOR_POWER_WARMUP_MS = 3000;

// Change button active duration (currently 30 seconds)
static const uint32_t BUTTON_ACTIVE_TIME_MS = 30000;
```

No need to understand PlatformIO in depth—simply modify these constants and upload the firmware.

---

## 6. Backend API

The FastAPI backend provides RESTful endpoints for data ingestion and retrieval.

### Database Schema

**Table: measurements**
- `id`: Primary key
- `ts`: Timestamp (datetime)
- `sensor_name`: Sensor identifier (e.g., "MS8607", "H2S")
- `parameter`: Parameter name (e.g., "temperature_c", "h2s_ppm")
- `value`: Numeric reading
- `unit`: Unit of measurement
- `status`: Sensor status ("online", "offline", "warming_up")

### API Endpoints

| Endpoint | Method | Description |
|---|---|---|
| `/api/ingest` | POST | Receive sensor data from ESP32 |
| `/api/sensors/current` | GET | Latest reading for all sensors |
| `/api/sensors/history` | GET | Historical data for charts |
| `/api/overview` | GET | System statistics (total sensors, online/offline counts) |

### Key Features

- **Automatic status tracking**: Backend infers online/offline based on 10-second threshold
- **Always shows last values**: Even offline sensors display their most recent readings
- **Flexible querying**: History endpoint supports custom time ranges
- **CORS enabled**: Dashboard can connect from any origin (configurable)

---

## 7. Web Dashboard

The React-based dashboard provides real-time monitoring and historical analysis.

### Features

1. **Sensor Overview Page**:
   - Grid of sensor cards showing latest readings
   - Green/gray status indicators
   - "Last seen" timestamps
   - Filter by category (Environment, Gas, Soil, Temperature, Light)

2. **Sensor Detail Page**:
   - Historical charts with configurable time range
   - Min/Max/Average statistics
   - Multiple parameters per sensor
   - Real-time updates

3. **Overview Dashboard**:
   - Total sensors count
   - Online/offline statistics
   - 24-hour averages
   - Total measurements count

### Setup

1. Install dependencies:
   ```bash
   npm install
   ```

2. Configure backend URL in `.env`:
   ```
   VITE_BACKEND_URL=http://YOUR_PC_IP:8000
   ```

3. Run development server:
   ```bash
   npm run dev
   ```

4. Access at `http://localhost:5173`

---

## 8. Setup Quick Start

### Prerequisites

- **Firmware**: PlatformIO (VS Code extension or CLI)
- **Backend**: Python 3.8+ with pip
- **Dashboard**: Node.js 16+ with npm

### Step-by-Step Setup

#### 1. Configure Firmware

Edit `src/config.h`:
```cpp
#define WIFI_SSID "YourWiFiNetwork"
#define WIFI_PASSWORD "YourPassword"
#define BACKEND_URL "http://YOUR_PC_IP:8000/api/ingest"
```

Upload to ESP32-S3 via PlatformIO.

#### 2. Start Backend

```bash
cd plant-sensor-backend
pip install -r requirements.txt
python -m uvicorn main:app --reload --host 0.0.0.0 --port 8000
```

Backend runs on `http://0.0.0.0:8000`

#### 3. Start Dashboard

```bash
cd Plant-Sensor-Network-Web-Dashboard
npm install
npm run dev
```

Dashboard opens at `http://localhost:5173`

#### 4. Power On ESP32

Device will:
- Connect to WiFi
- Perform initial measurement
- Send data to backend
- Enter deep sleep for 30 minutes
- Wake up automatically and repeat

---

## 9. Data Storage and Retention

### Estimated Database Growth

**Per measurement cycle (13 sensors, ~40 parameters)**:
- Database size: ~2 KB per cycle

**Daily storage** (30-minute intervals):
- 48 cycles/day × 2 KB = **96 KB/day**

**Monthly storage**:
- 30 days × 96 KB = **2.88 MB/month**

**Annual storage**:
- 12 months × 2.88 MB = **~35 MB/year**

SQLite can handle this easily. For long-term deployments, consider implementing data archiving or aggregation after 6-12 months.

---

## 10. Known Limitations and Future Enhancements

### Current Limitations

1. **Gas Sensor Testing**: NH₃, CH₄, and CO sensors are functional but not fully validated with target gases due to safety constraints
2. **WiFi Dependency**: System requires WiFi for data upload (no local storage fallback)
3. **Fixed Sample Rate**: 30-minute interval is hardcoded (requires recompilation to change)

### Potential Enhancements

- Local SD card logging for offline operation
- Battery voltage monitoring with low-battery alerts
- Configurable sample rates via web dashboard

---

## 11. Troubleshooting

### ESP32 Not Connecting to WiFi

- Verify WiFi credentials in `config.h`
- Check that backend URL is correct and reachable
- Ensure PC firewall allows connections on port 8000
- LED will blink rapidly if WiFi fails

### Backend API Errors

- Check backend console for error messages
- Verify SQLite database exists in backend folder
- Restart backend server: `Ctrl+C` then rerun uvicorn command

### Dashboard Shows No Data

- Verify `VITE_BACKEND_URL` in `.env` matches backend IP
- Check browser console (F12) for network errors
- Confirm backend is running and accessible at specified URL

### Sensor Readings Show "Offline"

- Check if 10 seconds have passed since last transmission
- Verify sensor connections and I²C bus wiring
- Review serial monitor output for sensor initialization errors

---

## 12. Additional Resources

### Official Documentation

- **DFRobot Sensors**: https://www.dfrobot.com/ – Detailed datasheets, calibration guides, and technical specifications
- **ESP32-S3**: https://docs.espressif.com/projects/esp-idf/en/latest/esp32s3/ – Deep sleep, GPIO, and peripheral documentation
- **FastAPI**: https://fastapi.tiangolo.com/ – Backend API framework documentation
- **React**: https://react.dev/ – Frontend framework documentation

---

## 13. Final Notes

This project represents a complete, production-ready IoT sensor monitoring system with professional-grade power management and data reliability.

The deep sleep implementation provides approximately **70% power savings** compared to an always-on design, making the system suitable for battery-powered deployments lasting weeks or months depending on battery capacity.

All sensors have been tested to the extent safely possible in a development environment. For sensors requiring hazardous gases (NH₃, CH₄, CO), the electronic interfaces and communication protocols have been validated—actual gas response curves can be confirmed by referring to DFRobot's official calibration data.

If you have any questions during setup, deployment, or while extending the system, please feel free to reach out. I would be happy to provide additional support or collaborate on future enhancements.

Thank you again for the opportunity to work on this project. It has been a pleasure developing this comprehensive monitoring solution.

---

**Document Version**: 1.0  
**Last Updated**: February 2026  
**Project Status**: Production Ready

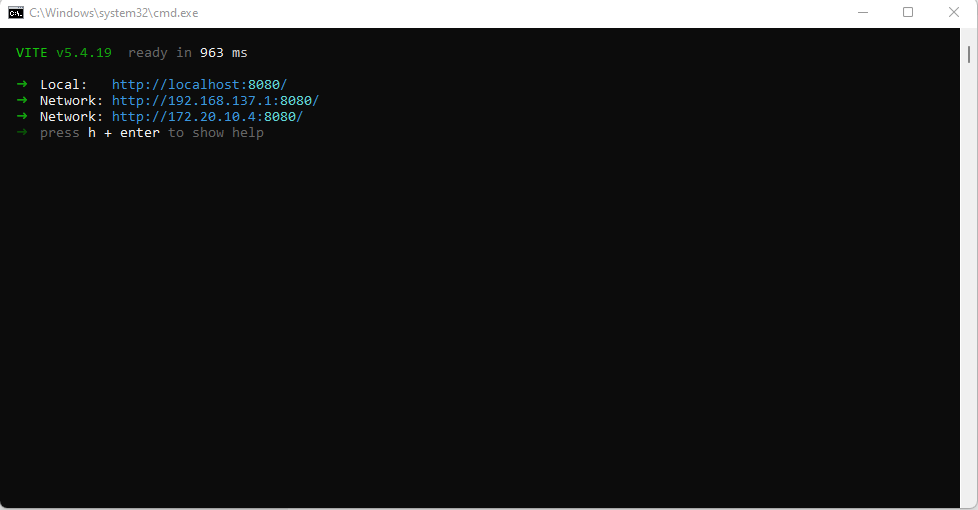
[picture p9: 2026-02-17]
Images/npm runing.png

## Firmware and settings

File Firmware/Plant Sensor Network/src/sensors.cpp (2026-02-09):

#include <Arduino.h>
#include <Wire.h>
#include <Adafruit_MS8607.h>
#include <Adafruit_Sensor.h>
#include <BH1750.h>
#include <DFRobot_Alcohol.h>
#include <DFRobot_MultiGasSensor.h>
#include <DFRobot_MHZ9041A.h>
#include <DFRobot_MLX90614.h>
#include <Adafruit_seesaw.h>
#include "DFRobotHCHOSensor.h"

// WiFi + HTTP JSON backend
#include <WiFi.h>
#include <HTTPClient.h>
#include <ArduinoJson.h>
#include "config.h"   // defines WIFI_SSID, WIFI_PASSWORD, BACKEND_URL

// Deep sleep support for ESP32-S3
#include <esp_sleep.h>
#include <driver/gpio.h>  // For gpio_hold_en/dis functions

// ESP32-S3 custom I2C pins
static const int SDA_PIN = 8;
static const int SCL_PIN = 9;

// MOSFET gate controlling 5V sensor power rail
// HIGH  = sensors powered
// LOW   = sensors off (power saving)
static const int SENSOR_MOSFET_PIN = 14;

// Wake-up button pin (press to wake from deep sleep and send data)
static const int WAKE_BUTTON_PIN = 7;

// Status LED pin (indicates device active/wifi status)
static const int STATUS_LED_PIN = 21;

// Sampling / power-control timing (can be tuned)
// Time between the start of measurement cycles (sensor power ON events)
static const uint32_t SENSOR_SAMPLE_INTERVAL_MS = 1800000; // 30 minutes (1,800,000 ms)
// Warm-up time after enabling 5V before reading sensors
static const uint32_t SENSOR_POWER_WARMUP_MS   = 3000;  // 3 seconds

// Deep sleep configuration
// Conversion: microseconds = milliseconds * 1000
static const uint64_t DEEP_SLEEP_INTERVAL_US = SENSOR_SAMPLE_INTERVAL_MS * 1000ULL;
// Time to stay awake after button wake (30 seconds)
static const uint32_t BUTTON_ACTIVE_TIME_MS = 30000;

// MultiGas read / offline behavior tuning
static const uint8_t  MULTIGAS_READ_MAX_RETRIES     = 3;    // retries within a single cycle
static const uint16_t MULTIGAS_READ_RETRY_DELAY_MS  = 100;  // delay between retries
static const uint8_t  SENSOR_MAX_FAIL_CYCLES        = 3;    // cycles before declaring sensor offline

// Mux addresses (TCA9548A / PCA9548A) typically 0x70-0x77
static const uint8_t POSSIBLE_MUX_ADDRS[] = {0x70, 0x71, 0x72, 0x73, 0x74, 0x75, 0x76, 0x77};
static const uint8_t MAX_MUXES = sizeof(POSSIBLE_MUX_ADDRS) / sizeof(POSSIBLE_MUX_ADDRS[0]);

// MS8607 is usually two I2C devices behind the module
static const uint8_t MS8607_HUM_ADDR  = 0x40;
static const uint8_t MS8607_PRES_ADDR = 0x76;

// BH1750 light sensor addresses (depends on ADDR pin)
static const uint8_t BH1750_ADDR_LOW  = 0x23;
static const uint8_t BH1750_ADDR_HIGH = 0x5C;

// DFRobot Alcohol (SEN0376) I2C addresses (set by onboard switches)
// From DFRobot docs: ADDRESS_0=0x72, ADDRESS_1=0x73, ADDRESS_2=0x74, ADDRESS_3=0x75
static const uint8_t ALCOHOL_ADDRS[] = {0x72, 0x73, 0x74, 0x75};
static const uint8_t ALCOHOL_ADDRS_LEN = sizeof(ALCOHOL_ADDRS) / sizeof(ALCOHOL_ADDRS[0]);

// DFRobot MultiGasSensor default I2C address is 0x74 (library default).
// It can also be configured, but we scan a small range to help locate it.
static const uint8_t MULTIGAS_ADDRS[] = {0x74, 0x75};
static const uint8_t MULTIGAS_ADDRS_LEN = sizeof(MULTIGAS_ADDRS) / sizeof(MULTIGAS_ADDRS[0]);

// MH-Z9041A CH4 sensor (DFRobot SEN0654)
// The DFRobot example uses I2C address 0x34, but the library header defaults to 0x75.
// To be robust, we scan both.
static const uint8_t CH4_ADDRS[] = {0x34, 0x75};
static const uint8_t CH4_ADDRS_LEN = sizeof(CH4_ADDRS) / sizeof(CH4_ADDRS[0]);
static const uint8_t CH4_PREFERRED_CH = 5; // your wiring

// MLX90614 IR thermometer (DFRobot SEN0206/SEN0263)
static const uint8_t MLX90614_DEFAULT_ADDR = 0x5A; // default I2C address

// Adafruit STEMMA Soil moisture sensor (Adafruit Seesaw)
static const uint8_t SOIL_CAP_I2C_ADDR = 0x36;     // default seesaw I2C address

static Adafruit_MS8607 ms8607;
static BH1750 bh1750;
// Pass explicit SDA/SCL pins so the MLX90614 library does not try to use
// an invalid default GPIO when toggling the I2C lines for wake-up.
static DFRobot_MLX90614_I2C mlx90614(MLX90614_DEFAULT_ADDR, &Wire, SDA_PIN, SCL_PIN);   // IR temperature sensor
static Adafruit_seesaw soilCapSeesaw;              // capacitive soil moisture (STEMMA Soil)
// Allocate after auto-detection so we can set the correct address
static DFRobot_Alcohol_I2C *alcohol = nullptr;

// MultiGas probes
// - H2S probe on mux_a (0x70)
// - O2, NH3, CO, O3 probes on mux_b (0x71)
static DFRobot_GAS_I2C *multigasH2S = nullptr;
static DFRobot_GAS_I2C *multigasO2 = nullptr;
static DFRobot_GAS_I2C *multigasNH3 = nullptr;
static DFRobot_GAS_I2C *multigasCO  = nullptr;
static DFRobot_GAS_I2C *multigasO3  = nullptr;

// MH-Z9041A CH4 - allocate after detection
static DFRobot_MHZ9041A_I2C *ch4 = nullptr;

// RS485 Soil EC + pH sensor (DFRobot SEN0603)
static const int RS485_RX_PIN = 19;
static const int RS485_TX_PIN = 20;
static HardwareSerial RS485Serial(2);

// Modbus-RTU query frame for this sensor (address 0x01, function 0x03,
// start register 0x0000, length 0x0004, CRC = 0x4409 (low, high)).
static uint8_t soilQueryFrame[8] = { 0x01, 0x03, 0x00, 0x00, 0x00, 0x04, 0x44, 0x09 };

static float soilEcMsPerCm = 0.0f;
static float soilPh = 0.0f;

// DFRobot HCHO sensor (UART, single "S" pin)
static const int HCHO_RX_PIN = 5;   // GPIO receiving data from sensor S
static HardwareSerial HCHO_Serial(1);
static DFRobotHCHOSensor hcho(&HCHO_Serial);
static float hchoPpm = 0.0f;

// --- WiFi helpers ----------------------------------------------------------
static void connectWiFi() {
  WiFi.mode(WIFI_STA);
  WiFi.begin(WIFI_SSID, WIFI_PASSWORD);

  Serial.print(F("Connecting to WiFi"));
  unsigned long start = millis();
  while (WiFi.status() != WL_CONNECTED && (millis() - start) < 30000UL) {
    Serial.print('.');
    delay(500);
  }
  Serial.println();

  if (WiFi.status() == WL_CONNECTED) {
    Serial.print(F("WiFi connected, IP="));
    Serial.println(WiFi.localIP());
    // WiFi connected - LED stays solid ON
    digitalWrite(STATUS_LED_PIN, HIGH);
  } else {
    Serial.println(F("WiFi connect FAILED (continuing, but no backend POSTs)."));
    // WiFi failed - blink LED to indicate error
    for (int i = 0; i < 5; i++) {
      digitalWrite(STATUS_LED_PIN, HIGH);
      delay(200);
      digitalWrite(STATUS_LED_PIN, LOW);
      delay(200);
    }
    // Keep LED blinking slowly while awake without WiFi
    digitalWrite(STATUS_LED_PIN, HIGH);
  }
}

static bool i2cPing(uint8_t address) {
  Wire.beginTransmission(address);
  return (Wire.endTransmission() == 0);
}

// Forward declarations (used by the presence-check helpers below)
static void muxDisableAll(uint8_t muxAddr);
static void muxSelectChannel(uint8_t muxAddr, uint8_t channel);
static void enterDeepSleep();

static bool ms8607Present(uint8_t muxAddr, uint8_t ch) {
  muxSelectChannel(muxAddr, ch);
  delay(3);
  return i2cPing(MS8607_HUM_ADDR) && i2cPing(MS8607_PRES_ADDR);
}

static bool bh1750Present(uint8_t muxAddr, uint8_t ch, uint8_t bhAddr) {
  muxSelectChannel(muxAddr, ch);
  delay(3);
  return i2cPing(bhAddr);
}

static bool alcoholPresent(uint8_t muxAddr, uint8_t ch, uint8_t addr) {
  muxSelectChannel(muxAddr, ch);
  delay(3);
  return i2cPing(addr);
}

static bool soilCapPresent(uint8_t muxAddr, uint8_t ch, uint8_t addr) {
  muxSelectChannel(muxAddr, ch);
  delay(3);
  return i2cPing(addr);
}

static bool mlx90614Present(uint8_t muxAddr, uint8_t ch) {
  muxSelectChannel(muxAddr, ch);
  delay(3);
  return i2cPing(MLX90614_DEFAULT_ADDR);
}

static bool multigasPresent(uint8_t muxAddr, uint8_t ch, uint8_t addr) {
  muxSelectChannel(muxAddr, ch);
  delay(3);
  return i2cPing(addr);
}

static bool ch4Present(uint8_t muxAddr, uint8_t ch, uint8_t ch4Addr) {
  muxSelectChannel(muxAddr, ch);
  delay(3);
  return i2cPing(ch4Addr);
}

static void muxDisableAll(uint8_t muxAddr) {
  Wire.beginTransmission(muxAddr);
  Wire.write(0x00);
  Wire.endTransmission();
}

static void muxSelectChannel(uint8_t muxAddr, uint8_t channel) {
  if (channel > 7) return;

  // IMPORTANT: Disable all channels on BOTH muxes before enabling one channel.
  // Otherwise, two downstream busses can be connected at the same time and devices
  // with the same I2C address (like MultiGas at 0x74) will collide and cause bad reads.
  muxDisableAll(0x70);
  muxDisableAll(0x71);

  Wire.beginTransmission(muxAddr);
  Wire.write(1 << channel);
  Wire.endTransmission();
}


static bool findMs8607Location(uint8_t *outMuxAddr, uint8_t *outChannel) {
  for (uint8_t i = 0; i < MAX_MUXES; i++) {
    const uint8_t muxAddr = POSSIBLE_MUX_ADDRS[i];
    if (!i2cPing(muxAddr)) {
      continue;
    }

    muxDisableAll(muxAddr);
    delay(2);

    for (uint8_t ch = 0; ch < 8; ch++) {
      muxSelectChannel(muxAddr, ch);
      delay(3);

      // MS8607 module normally exposes both 0x40 and 0x76
      const bool humOk  = i2cPing(MS8607_HUM_ADDR);
      const bool presOk = i2cPing(MS8607_PRES_ADDR);

      if (humOk && presOk) {
        *outMuxAddr = muxAddr;
        *outChannel = ch;
        muxDisableAll(muxAddr);
        return true;
      }
    }

    muxDisableAll(muxAddr);
  }

  return false;
}

static bool findBh1750Location(uint8_t *outMuxAddr, uint8_t *outChannel, uint8_t *outBhAddr) {
  for (uint8_t i = 0; i < MAX_MUXES; i++) {
    const uint8_t muxAddr = POSSIBLE_MUX_ADDRS[i];
    if (!i2cPing(muxAddr)) {
      continue;
    }

    muxDisableAll(muxAddr);
    delay(2);

    for (uint8_t ch = 0; ch < 8; ch++) {
      muxSelectChannel(muxAddr, ch);
      delay(3);

      // BH1750 usually responds on 0x23 or 0x5C
      if (i2cPing(BH1750_ADDR_LOW)) {
        *outMuxAddr = muxAddr;
        *outChannel = ch;
        *outBhAddr  = BH1750_ADDR_LOW;
        muxDisableAll(muxAddr);
        return true;
      }

      if (i2cPing(BH1750_ADDR_HIGH)) {
        *outMuxAddr = muxAddr;
        *outChannel = ch;
        *outBhAddr  = BH1750_ADDR_HIGH;
        muxDisableAll(muxAddr);
        return true;
      }
    }

    muxDisableAll(muxAddr);
  }

  return false;
}

static bool findAlcoholLocation(uint8_t *outMuxAddr, uint8_t *outChannel, uint8_t *outAlcoholAddr) {
  // Your wiring: Alcohol sensor is on channel 7.
  // We search ch7 first to avoid confusing it with other sensors that may share addresses on other channels.
  static const uint8_t PREFERRED_CH = 7;

  for (uint8_t i = 0; i < MAX_MUXES; i++) {
    const uint8_t muxAddr = POSSIBLE_MUX_ADDRS[i];
    if (!i2cPing(muxAddr)) {
      continue;
    }

    // 1) Try preferred channel first
    muxDisableAll(muxAddr);
    delay(2);
    muxSelectChannel(muxAddr, PREFERRED_CH);
    delay(3);

    for (uint8_t ai = 0; ai < ALCOHOL_ADDRS_LEN; ai++) {
      uint8_t addr = ALCOHOL_ADDRS[ai];
      if (i2cPing(addr)) {
        *outMuxAddr = muxAddr;
        *outChannel = PREFERRED_CH;
        *outAlcoholAddr = addr;
        muxDisableAll(muxAddr);
        return true;
      }
    }

    // 2) Fallback: scan all channels
    for (uint8_t ch = 0; ch < 8; ch++) {
      if (ch == PREFERRED_CH) continue;
      muxSelectChannel(muxAddr, ch);
      delay(3);

      for (uint8_t ai = 0; ai < ALCOHOL_ADDRS_LEN; ai++) {
        uint8_t addr = ALCOHOL_ADDRS[ai];
        if (i2cPing(addr)) {
          *outMuxAddr = muxAddr;
          *outChannel = ch;
          *outAlcoholAddr = addr;
          muxDisableAll(muxAddr);
          return true;
        }
      }
    }

    muxDisableAll(muxAddr);
  }

  return false;
}

static bool findCh4Location(uint8_t *outMuxAddr, uint8_t *outChannel, uint8_t *outCh4Addr) {
  // CH4 sensor is on channel 5 (your wiring). Try ch5 first.
  for (uint8_t i = 0; i < MAX_MUXES; i++) {
    const uint8_t muxAddr = POSSIBLE_MUX_ADDRS[i];
    if (!i2cPing(muxAddr)) continue;

    muxDisableAll(muxAddr);
    delay(2);

    // 1) preferred channel
    muxSelectChannel(muxAddr, CH4_PREFERRED_CH);
    delay(3);
    for (uint8_t ai = 0; ai < CH4_ADDRS_LEN; ai++) {
      const uint8_t addr = CH4_ADDRS[ai];
      if (i2cPing(addr)) {
        *outMuxAddr = muxAddr;
        *outChannel = CH4_PREFERRED_CH;
        *outCh4Addr = addr;
        muxDisableAll(muxAddr);
        return true;
      }
    }

    // 2) fallback scan
    for (uint8_t ch = 0; ch < 8; ch++) {
      if (ch == CH4_PREFERRED_CH) continue;
      muxSelectChannel(muxAddr, ch);
      delay(3);
      for (uint8_t ai = 0; ai < CH4_ADDRS_LEN; ai++) {
        const uint8_t addr = CH4_ADDRS[ai];
        if (i2cPing(addr)) {
          *outMuxAddr = muxAddr;
          *outChannel = ch;
          *outCh4Addr = addr;
          muxDisableAll(muxAddr);
          return true;
        }
      }
    }

    muxDisableAll(muxAddr);
  }
  return false;
}
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
void loop() {
  // Track measurement cycle: 0 = not started, 1 = first cycle done, 2 = second cycle done
  static uint8_t measurementCycle = 0;
  static uint32_t lastCycleMs = 0;
  
  // Check wake-up reason to determine behavior
  static esp_sleep_wakeup_cause_t wakeup_reason = esp_sleep_get_wakeup_cause();
  static uint32_t buttonWakeStartMs = 0;
  static bool isButtonActiveMode = false;
  static bool buttonMeasurementDone = false;
  static bool buttonMessagePrinted = false;  // Prevent repeated message

  // If woken by button and haven't done measurement yet, proceed with measurement
  // After measurement completes, enter "active mode" for 30 seconds
  if (wakeup_reason == ESP_SLEEP_WAKEUP_EXT0 && !buttonMeasurementDone && !buttonMessagePrinted) {
    Serial.println(F("Button wake: running measurement cycles"));
    buttonMessagePrinted = true;
    // Fall through to run measurement cycle below
  }

  // In button active mode (after measurement), check if 30 seconds have elapsed
  if (isButtonActiveMode) {
    if (millis() - buttonWakeStartMs >= BUTTON_ACTIVE_TIME_MS) {
      Serial.println(F("Button active period ended, entering deep sleep"));
      // Reset flags for next wake
      isButtonActiveMode = false;
      buttonMeasurementDone = false;
      measurementCycle = 0;  // Reset cycle counter
      enterDeepSleep();
      return;  // Never reached, but explicit
    }
    
    // Blink LED slowly if WiFi not connected (to show device is awake but offline)
    if (WiFi.status() != WL_CONNECTED) {
      static uint32_t lastBlinkMs = 0;
      if (millis() - lastBlinkMs >= 1000) {  // Toggle every 1 second
        digitalWrite(STATUS_LED_PIN, !digitalRead(STATUS_LED_PIN));
        lastBlinkMs = millis();
      }
    } else {
      // WiFi connected - keep LED solid ON
      digitalWrite(STATUS_LED_PIN, HIGH);
    }
    
    // Stay awake, delay and loop
    delay(100);
    return;
  }
  
  // Check if we need to wait between cycles (for double measurement)
  if (measurementCycle == 1) {
    // Wait 2 seconds between first and second cycle
    if (millis() - lastCycleMs < 2000) {
      delay(100);
      return;
    }
    // Ready for second cycle
    Serial.println();
    Serial.println(F("========== SECOND CYCLE (POSTING TO BACKEND) =========="));
  }

  // Indicate which cycle this is
  if (measurementCycle == 0) {
    Serial.println();
    Serial.println(F("========== FIRST CYCLE (STATUS CHECK ONLY) =========="));
  }
  
  // Power ON all sensors via MOSFET gate and allow them to stabilise.
  digitalWrite(SENSOR_MOSFET_PIN, HIGH);
  delay(SENSOR_POWER_WARMUP_MS);

  Serial.println();
  Serial.println(F("--- cycle ---"));

  // Reset per-cycle sensor counters
  resetSensorCounters();

  // JSON payload for backend ingest
  // Use global StaticJsonDocument to keep it off the stack. Clear it at the
  // start of each cycle.
  doc.clear();
  doc["ts_ms"] = millis();

  static bool msInitialized = false;
  static bool bhInitialized = false;
  static bool alcoholInitialized = false;
  static bool multigasH2SInitialized = false;
  static bool multigasO2Initialized = false;
  static bool multigasNH3Initialized = false;
  static bool multigasCOInitialized  = false;
  static bool multigasO3Initialized  = false;
  static bool ch4Initialized = false;
  static bool mlxInitialized = false;
  static bool soilCapInitialized = false;
  static bool soilInitialized = false;
  static bool hchoInitialized = false;

  // Because the 5V sensor rail is power-cycled each measurement cycle via
  // SENSOR_MOSFET_PIN, force re-initialisation of all sensors on each cycle
  // after power-on. This makes sure I2C/UART configuration is restored after
  // the modules have lost power.
  msInitialized = false;
  bhInitialized = false;
  alcoholInitialized = false;
  multigasH2SInitialized = false;
  multigasO2Initialized = false;
  multigasNH3Initialized = false;
  multigasCOInitialized  = false;
  multigasO3Initialized  = false;
  ch4Initialized = false;
  mlxInitialized = false;
  soilCapInitialized = false;
  soilInitialized = false;
  hchoInitialized = false;

  // Track whether a sensor was ever connected before (to distinguish "not_found" vs "not_connected")
  static bool msEverConnected = false;
  static bool bhEverConnected = false;
  static bool alcoholEverConnected = false;
  static bool multigasH2SEverConnected = false;
  static bool multigasO2EverConnected = false;
  static bool multigasNH3EverConnected = false;
  static bool multigasCOEverConnected  = false;
  static bool multigasO3EverConnected  = false;
  static bool ch4EverConnected = false;
  static bool mlxEverConnected = false;
  static bool soilCapEverConnected = false;
  static bool soilEverConnected = false;
  static bool hchoEverConnected = false;

  // Track consecutive read failures per MultiGas sensor. We only mark the
  // sensor truly offline if it fails SENSOR_MAX_FAIL_CYCLES times in a row.
  static uint8_t multigasH2SFailCycles = 0;
  static uint8_t multigasO2FailCycles  = 0;
  static uint8_t multigasNH3FailCycles = 0;
  static uint8_t multigasCOFailCycles  = 0;
  static uint8_t multigasO3FailCycles  = 0;

  static uint8_t msMuxAddr = 0;
  static uint8_t msMuxChannel = 0;

  static uint8_t bhMuxAddr = 0;
  static uint8_t bhMuxChannel = 0;
  static uint8_t bhAddr = 0;

  static uint8_t alcoholMuxAddr = 0;
  static uint8_t alcoholMuxChannel = 0;
  static uint8_t alcoholAddr = 0;

  // MultiGas H2S on mux_a (0x70), preferred ch6
  static uint8_t gasH2SMuxAddr = 0x70;
  static uint8_t gasH2SChannel = 6;
  static uint8_t gasH2SAddr = 0;

  // MultiGas gases on mux_b (0x71)
  // From your wiring / scan:
  //   ch4 -> O2, ch5 -> NH3, ch6 -> CO, ch7 -> O3 (all at 0x74)
  static uint8_t gasO2MuxAddr  = 0x71;
  static uint8_t gasO2Channel  = 4;
  static uint8_t gasO2Addr     = 0;

  static uint8_t gasNH3MuxAddr = 0x71;
  static uint8_t gasNH3Channel = 5;
  static uint8_t gasNH3Addr    = 0;

  static uint8_t gasCOMuxAddr  = 0x71;
  static uint8_t gasCOChannel  = 6;
  static uint8_t gasCOAddr     = 0;

  static uint8_t gasO3MuxAddr  = 0x71;
  static uint8_t gasO3Channel  = 7;
  static uint8_t gasO3Addr     = 0;

  static uint8_t ch4MuxAddr = 0;
  static uint8_t ch4MuxChannel = 0;
  static uint8_t ch4Addr = 0;

  // MLX90614 IR thermometer on mux_b (0x71), auto-detected channel
  static uint8_t mlxMuxAddr   = 0x71;
  static uint8_t mlxChannel   = 0;

  // STEMMA Soil capacitive moisture sensor (Adafruit Seesaw) on mux_b (0x71)
  static uint8_t soilCapMuxAddr   = 0x71;
  static uint8_t soilCapChannel   = 1;   // preferred channel, auto-adjusted after scan
  static uint8_t soilCapAddr      = SOIL_CAP_I2C_ADDR;

  // Measurement cycle tracking is now handled by measurementCycle variable
  // - Cycle 0: First measurement (status check only)
  // - Cycle 1: Second measurement (POST to backend)

  // ---- Init MS8607 once (auto-detect) ----
  if (!msInitialized) {
    if (!findMs8607Location(&msMuxAddr, &msMuxChannel)) {
      printStatusLine("MS8607", 0x00, 255, msEverConnected ? "not_connected" : "not_found");
      trackSensorStatus("MS8607", false);
    } else {
      muxSelectChannel(msMuxAddr, msMuxChannel);
      delay(5);

      if (!ms8607.begin()) {
        printStatusLine("MS8607", msMuxAddr, msMuxChannel, "begin_failed");
        trackSensorStatus("MS8607", false);
      } else {
        msInitialized = true;
        msEverConnected = true;
      }
    }
  }

  // ---- Init BH1750 once (auto-detect) ----
  if (!bhInitialized) {
    if (!findBh1750Location(&bhMuxAddr, &bhMuxChannel, &bhAddr)) {
      printStatusLine("BH1750", 0x00, 255, bhEverConnected ? "not_connected" : "not_found");
      trackSensorStatus("BH1750", false);
    } else {
      muxSelectChannel(bhMuxAddr, bhMuxChannel);
      delay(5);

      // Use continuous high-res mode for stable readings
      if (!bh1750.begin(BH1750::CONTINUOUS_HIGH_RES_MODE, bhAddr, &Wire)) {
        printStatusLine("BH1750", bhMuxAddr, bhMuxChannel, "begin_failed");
        trackSensorStatus("BH1750", false);
      } else {
        bhInitialized = true;
        bhEverConnected = true;
      }
    }
  }

  // ---- Init Alcohol sensor once (auto-detect) ----
  if (!alcoholInitialized) {
    if (!findAlcoholLocation(&alcoholMuxAddr, &alcoholMuxChannel, &alcoholAddr)) {
      printStatusLine("ALCOHOL", 0x00, 255, alcoholEverConnected ? "not_connected" : "not_found");
      trackSensorStatus("ALCOHOL", false);
    } else {
      muxSelectChannel(alcoholMuxAddr, alcoholMuxChannel);
      delay(5);

      // Recreate driver if address changed
      if (alcohol != nullptr) {
        delete alcohol;
        alcohol = nullptr;
      }
      alcohol = new DFRobot_Alcohol_I2C(&Wire, alcoholAddr);
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

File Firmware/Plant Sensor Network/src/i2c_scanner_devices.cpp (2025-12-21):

#include <Arduino.h>
#include <Wire.h>

// ESP32-S3 custom I2C pins
static const int SDA_PIN = 8;
static const int SCL_PIN = 9;

// Visual debug LED (you said you're disconnecting USB)
static const int LED_PIN = 19;

static const uint16_t LED_ON_MS  = 180;
static const uint16_t LED_OFF_MS = 180;
static const uint16_t LED_PAUSE_MS_AFTER_CYCLE = 5000;

// TCA9548A / PCA9548A muxes typically live at 0x70-0x77 (A0/A1/A2 strap pins)
static const uint8_t POSSIBLE_MUX_ADDRS[] = {0x70, 0x71, 0x72, 0x73, 0x74, 0x75, 0x76, 0x77};
static const uint8_t MAX_MUXES = sizeof(POSSIBLE_MUX_ADDRS) / sizeof(POSSIBLE_MUX_ADDRS[0]);

static bool i2cPing(uint8_t address) {
  Wire.beginTransmission(address);
  return (Wire.endTransmission() == 0);
}

static bool isInList(uint8_t value, const uint8_t *list, uint8_t listLen) {
  for (uint8_t i = 0; i < listLen; i++) {
    if (list[i] == value) return true;
  }
  return false;
}

static void muxDisableAll(uint8_t muxAddr) {
  Wire.beginTransmission(muxAddr);
  Wire.write(0x00); // no channel selected
  Wire.endTransmission();
}

static void muxSelectChannel(uint8_t muxAddr, uint8_t channel) {
  if (channel > 7) return;
  Wire.beginTransmission(muxAddr);
  Wire.write(1 << channel);
  Wire.endTransmission();
}

static uint8_t detectMuxes(uint8_t *foundMuxAddrs, uint8_t maxFound) {
  uint8_t count = 0;
  for (uint8_t i = 0; i < MAX_MUXES && count < maxFound; i++) {
    uint8_t addr = POSSIBLE_MUX_ADDRS[i];
    if (i2cPing(addr)) {
      foundMuxAddrs[count++] = addr;
    }
  }
  return count;
}

static void blinkCount(uint16_t count) {
  // Blink count times. If count==0, do a single long blink to indicate "zero".
  if (count == 0) {
    digitalWrite(LED_PIN, HIGH);
    delay(800);
    digitalWrite(LED_PIN, LOW);
    return;
  }

  for (uint16_t i = 0; i < count; i++) {
    digitalWrite(LED_PIN, HIGH);
    delay(LED_ON_MS);
    digitalWrite(LED_PIN, LOW);
    delay(LED_OFF_MS);
  }
}

static uint8_t scanDevicesBehindMux(uint8_t muxIndex,
                                   uint8_t muxAddr,
                                   const uint8_t *allMuxAddrs,
                                   uint8_t muxCount) {
  Serial.println();
  Serial.print(F("=== MUX #"));
  Serial.print(muxIndex);
  Serial.print(F(" address 0x"));
  if (muxAddr < 16) Serial.print('0');
  Serial.print(muxAddr, HEX);
  Serial.println(F(" ==="));

  // Count devices as (channel + address).
  // - Same address on DIFFERENT channels counts as DIFFERENT devices (your requirement).
  // - Duplicate hits of same address within the SAME channel are counted once.
  uint8_t deviceCount = 0;

  muxDisableAll(muxAddr);
  delay(3);

  for (uint8_t ch = 0; ch < 8; ch++) {
    muxSelectChannel(muxAddr, ch);
    delay(3);

    bool anyOnChannel = false;
    bool seenOnChannel[128] = {false};

    for (uint8_t address = 1; address < 127; address++) {
      // Skip mux addresses so muxes don't appear as devices
      if (isInList(address, allMuxAddrs, muxCount)) {
        continue;
      }

      Wire.beginTransmission(address);
      uint8_t err = Wire.endTransmission();
      if (err == 0) {
        anyOnChannel = true;

        // Count this (channel,address) only once
        if (!seenOnChannel[address]) {
          seenOnChannel[address] = true;
          deviceCount++;
        }

        Serial.print(F("MUX #"));
        Serial.print(muxIndex);
        Serial.print(F(" (0x"));
        if (muxAddr < 16) Serial.print('0');
        Serial.print(muxAddr, HEX);
        Serial.print(F(") ch "));
        Serial.print(ch);
        Serial.print(F(" -> device 0x"));
        if (address < 16) Serial.print('0');
        Serial.println(address, HEX);
      }

      delay(2);
    }

    if (!anyOnChannel) {
      Serial.print(F("MUX #"));
      Serial.print(muxIndex);
      Serial.print(F(" ch "));
      Serial.print(ch);
      Serial.println(F(" -> (no devices)"));
    }
  }

  muxDisableAll(muxAddr);

  Serial.print(F("MUX #"));
  Serial.print(muxIndex);
  Serial.print(F(" devices (counted per-channel) = "));
  Serial.println(deviceCount);

  return deviceCount;
}

void setup() {
  pinMode(LED_PIN, OUTPUT);
  digitalWrite(LED_PIN, LOW);

  Serial.begin(115200);
  delay(1000);

  Serial.println();
  Serial.println(F("=== ESP32-S3 I2C Scanner (Mux + Devices) ==="));

  Wire.begin(SDA_PIN, SCL_PIN);
}

void loop() {
  uint8_t muxAddrs[8];
  uint8_t muxCount = detectMuxes(muxAddrs, 8);

  Serial.println();
  Serial.print(F("Detected mux count: "));
  Serial.println(muxCount);

  for (uint8_t i = 0; i < muxCount; i++) {
    Serial.print(F("  MUX #"));
    Serial.print(i + 1);
    Serial.print(F(" address = 0x"));
    if (muxAddrs[i] < 16) Serial.print('0');
    Serial.println(muxAddrs[i], HEX);
  }

  if (muxCount == 0) {
    Serial.println(F("No mux detected at 0x70-0x77."));
    delay(2000);
    return;
  }

  // Helpful warning for your use case (two muxes in parallel)
  if (muxCount == 1) {
    Serial.println(F("NOTE: If you connected TWO mux boards in parallel, they MUST have different I2C addresses (0x70-0x77)."));
  }

  // Ensure all muxes are disabled before scanning
  for (uint8_t i = 0; i < muxCount; i++) {
    muxDisableAll(muxAddrs[i]);
  }

  uint8_t totals[8] = {0};
  for (uint8_t i = 0; i < muxCount; i++) {
    totals[i] = scanDevicesBehindMux(i + 1, muxAddrs[i], muxAddrs, muxCount);
  }

  Serial.println();
  Serial.println(F("=== Summary (devices counted per-channel) ==="));
  uint16_t totalDevicesAllMuxes = 0;
  for (uint8_t i = 0; i < muxCount; i++) {
    Serial.print(F("MUX #"));
    Serial.print(i + 1);
    Serial.print(F(" (0x"));
    if (muxAddrs[i] < 16) Serial.print('0');
    Serial.print(muxAddrs[i], HEX);
    Serial.print(F(") devices = "));
    Serial.println(totals[i]);

    totalDevicesAllMuxes += totals[i];
  }

  // Visual debug:
  // Blink LED_PIN exactly "totalDevicesAllMuxes" times, then keep LED off for 5 seconds.
  // Example from your log: MUX1=5 and MUX2=1 => total=6 blinks.
  blinkCount(totalDevicesAllMuxes);
  digitalWrite(LED_PIN, LOW);

  Serial.println(F("\n=== Scan cycle complete ===\n"));
  delay(LED_PAUSE_MS_AFTER_CYCLE);
}

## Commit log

2025-11-24 Initial Comit !
    [BOM.xlsx, Plant Monitoring Sensor Network.xlsx]
2025-11-24 Working of O2 Sensor
2025-11-26 ------------------------------------------------
    MS8607 1 0 Temp 26.76 C
    MS8607 1 0 Humidity 27.95 %RH
    MS8607 1 0 Pressure 1011.82 hPa
    MLX90614 1 6 ObjTemp 24.89 C
    BH1750 2 3 Lux 0.00 lx
    MultiGas 1 7 O2 20.90 %vol
2025-11-26 Working !!
    BH1750 Lux Sensor
    MS8607 Pressure, Temp, Hum
    IR Temperature
    O2 .
2025-12-21 Added the Methane CH4 , LDR, Temp/Hum and H2S Sensor
    [BOM.xlsx]
2025-12-21 Integrated the oxygen Sensor
2026-01-07 integrating Multi gas Sensors and the previous sensors as well.
2026-01-25 Integrating RS-485 and the PH sensor along with the HCHO
2026-02-08 Integrated all the remaining sensors such as ir temp capacitive soil moisture and added deep sleep mode
2026-02-09 Documentation reorganization and hardware updates
    - Created 'Delivery Documents' folder for client documentation
    - Moved PROJECT_DELIVERY_DOCUMENTATION.md
    - Moved PROJECT_WORKFLOW_WIFI.md
    - Created comprehensive README.md for each component:
    - Firmware README with hardware specs and power consumption
    - Backend README (already existed, verified)
    - Web Dashboard README (new)
    - Updated main README.md as navigation hub
    - Removed duplicate/outdated documentation files
    - Updated hardware specifications:
    - Solar panel: 10W @ 18V (corrected from 12V)
    - Button: Internal pull-up (no external resistor)
    - Status LED: Blue LED with 4.7kΩ resistor
    - Added green power LEDs documentation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
    [sensors.cpp]
2026-02-17 Included the delivery files and folders.
    [BOM.xlsx, Plant Monitoring Sensor Network.xlsx]
2026-02-23 Added Schematic Folder
    [Plant_Sensor_Network.kicad_pcb, Plant_Sensor_Network.kicad_sch]
2026-03-19 Remove sensitive document: Documents/BOM.xlsx
    [BOM.xlsx]
2026-03-19 Remove sensitive document: Documents/Plant Monitoring Sensor Network.pdf
2026-03-19 Remove sensitive document: Documents/Plant Monitoring Sensor Network.xlsx
    [Plant Monitoring Sensor Network.xlsx]
